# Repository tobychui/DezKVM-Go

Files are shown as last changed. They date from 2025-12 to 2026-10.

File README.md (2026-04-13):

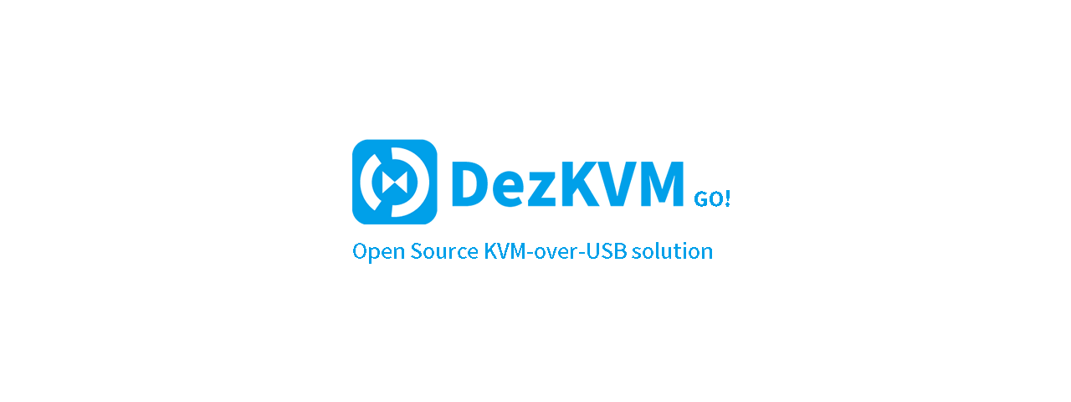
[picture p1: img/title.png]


# DezKVM-Go

A mini KVM over USB device for onsite engineers to use their laptop to control headless computers or servers.

If you are looking for an IP-KVM solution, take a look at the [DezKVM](https://github.com/tobychui/DezKVM) Project!

## Features

- Small form factor , just 84 x 53 x 18mm
- Cheap & Easy to build, costing just under $20 USD per unit
- Fully featured software that do not require installing any apps
  - Live video and audio feeds
  - Paste box (host to remote computer through automatic virtual keyboard HID events)
  - Copy via OCR (remote to host computer through OCR image to text conversion) 
  - On-screen keyboard
  - Commonly used Hot-key and macros
  - Take Screenshots
- Advanced Settings
  - Invert mouse scroll wheel direction (for Windows / MacOS cross control)
  - Absolute / Relative mode for mouse
  - Mouse Jiggler
  
## Usage

1. Insert the DezKVM-Go host side USB port into your laptop using a USB type-C cable (located on the white / black side, depends on your device casing color)
2. Insert the DezKVM-Go remote side USB port and HDMI port into the remote server or computer you want to control (located on the orange side)
3. Visit the [DezKVM-Go control panel](https://tobychui.github.io/DezKVM-Go/) or if you are working online, start the usbkvm application and visit `https://localhost:8443/` using Chrome, Edge or any Chromium browsers that support Web-Serial API.

## Quick Start

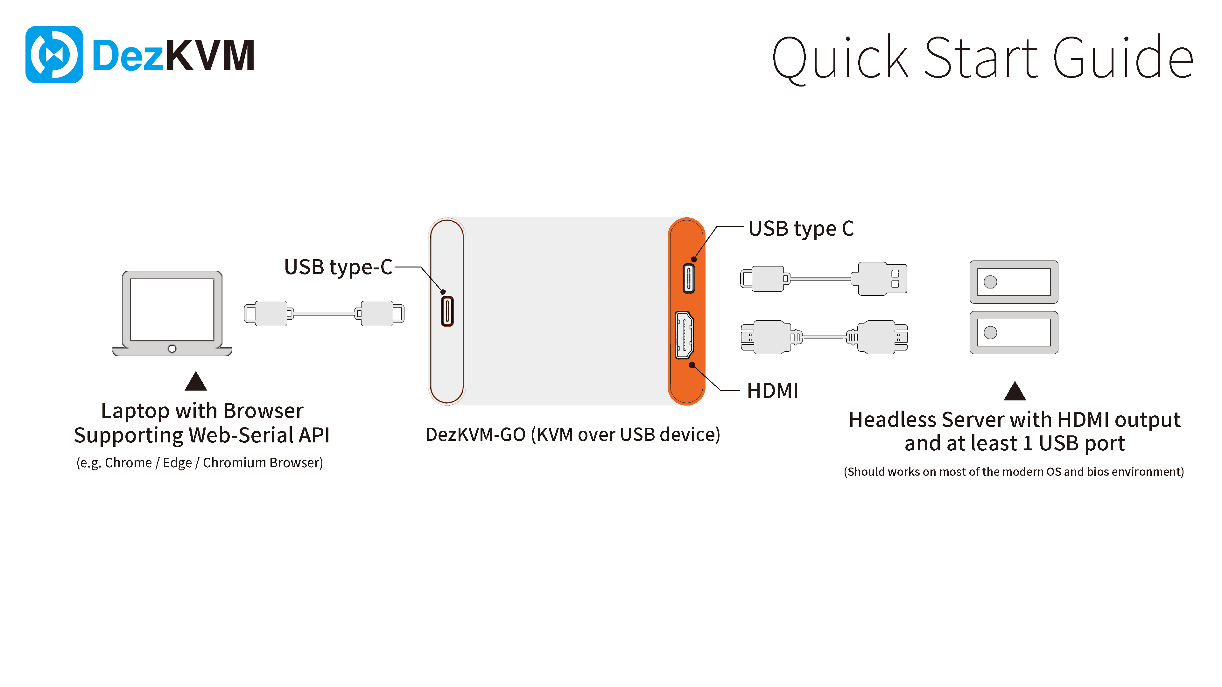
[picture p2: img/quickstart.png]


## Building the Hardware

To build the hardware, you will need the following items

- A DezKVM-Go PCB (See the `PCB` folder and the `how-to-place-order` folder on how to order them )
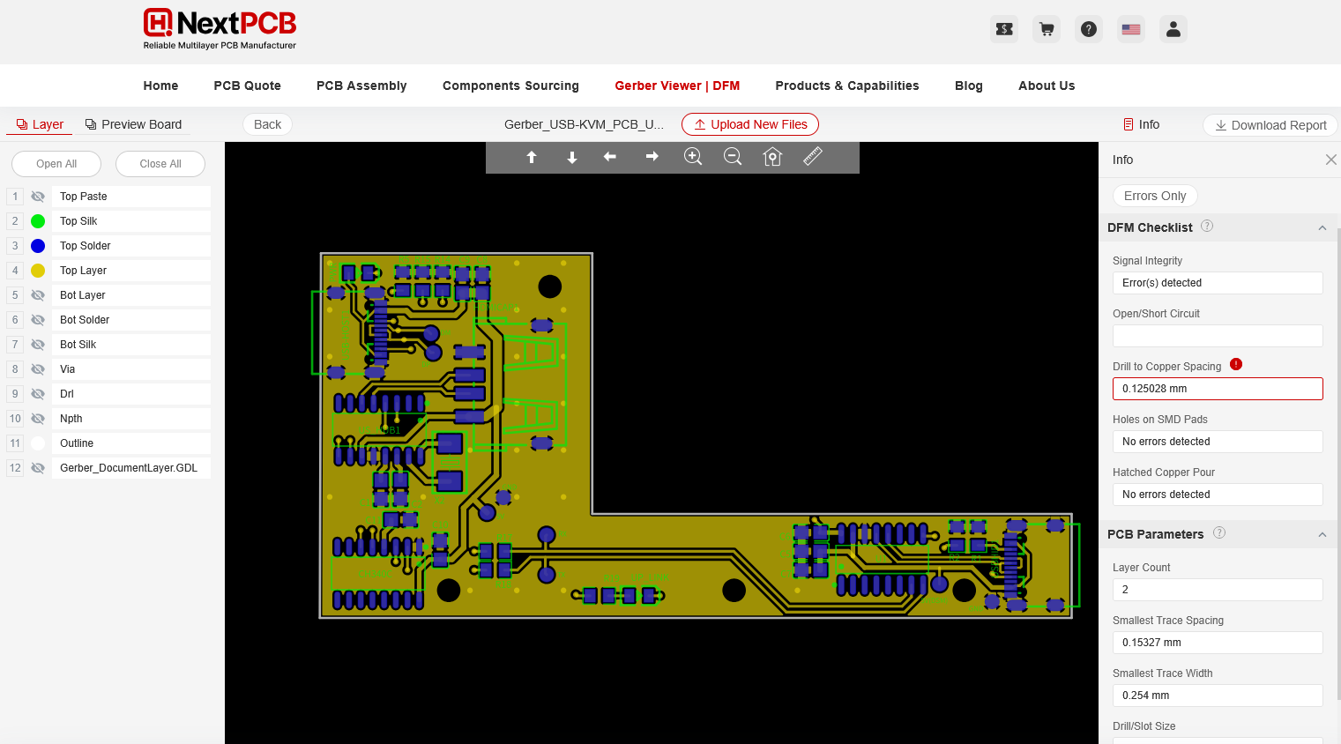
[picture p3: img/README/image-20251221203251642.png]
  
- A MS2109 HDMI capture card (usually around $7 - 9 USD a pcs)
- A 3D printer (for the case, see `3D Models` folder)
- M3x10 screws x 2
- USB type-C cable x 2 and HDMI cable x 1

For details, see the PCB folder.

## Building the Software

There is no need to build anything since all of the control code of this system is written in vanilla js in the web front-end. However, this project do come with a Golang written https server in which if you have difficulties deploying a website with https , you can use that https server to deploy a locally hosted version of the DezKVM viewer.

To build the local version of DezKVM viewer, follow the instruction below.

```bash
cd ./src
go mod tidy
go build
```

*Note: you will also need to configure the CH9329 chip to use the 115200 baudrate for the front-end to work. Please follow the instructions in CH9329 datasheet to perform the baudrate change procedures before use.*

## Screenshots

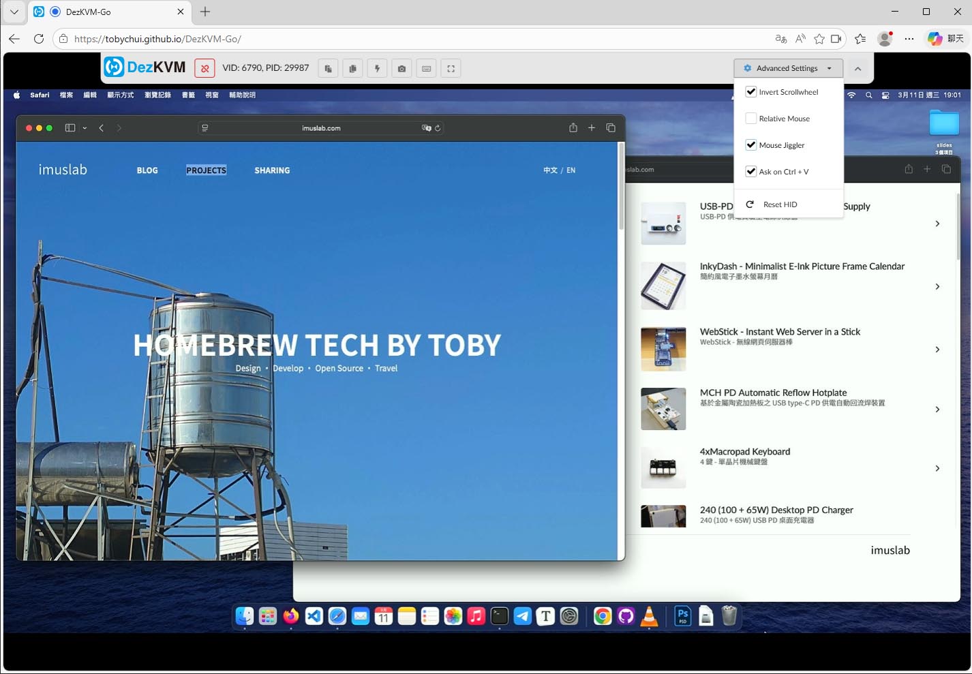
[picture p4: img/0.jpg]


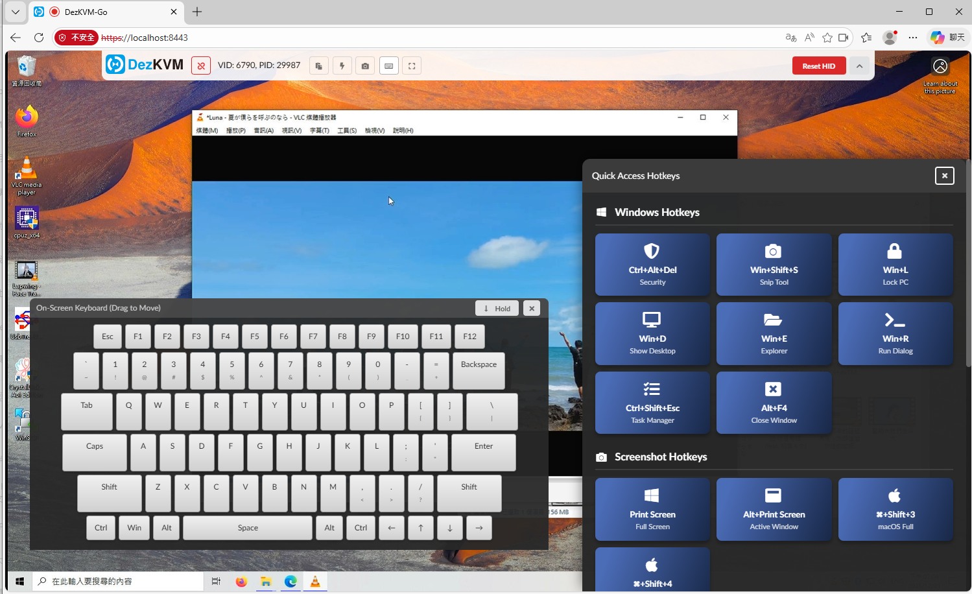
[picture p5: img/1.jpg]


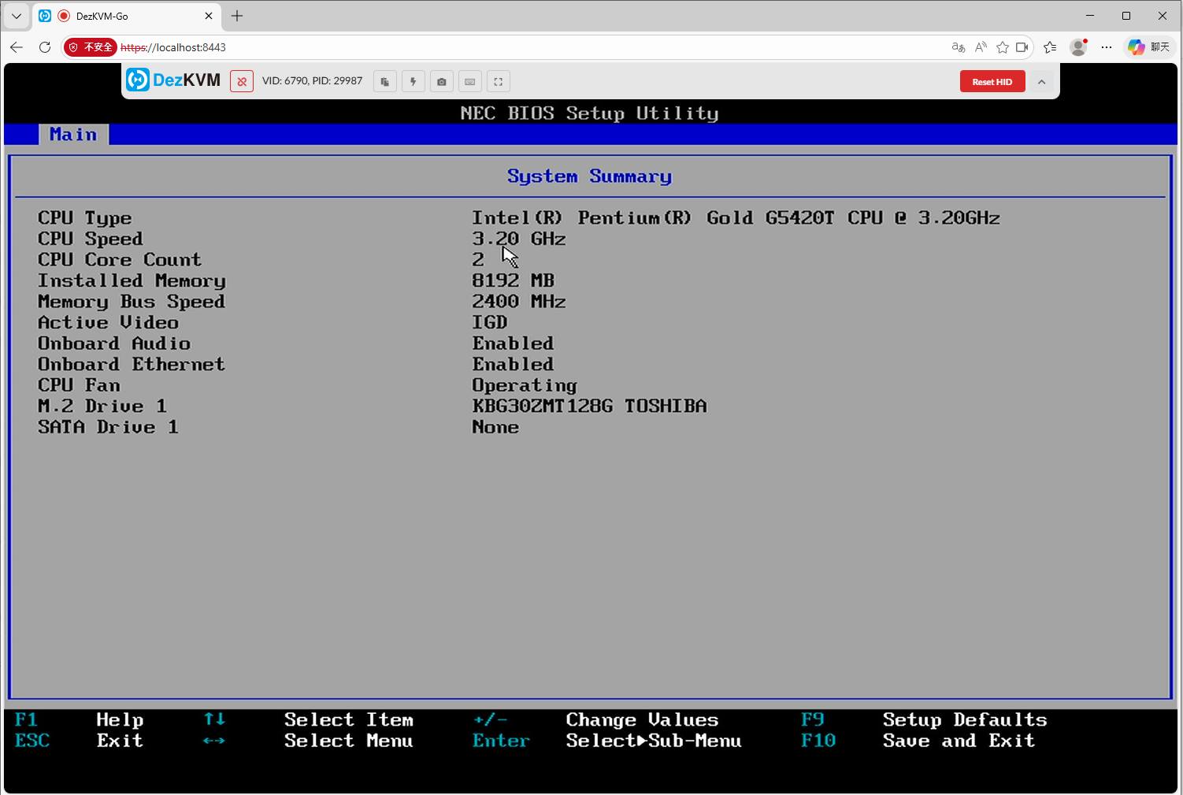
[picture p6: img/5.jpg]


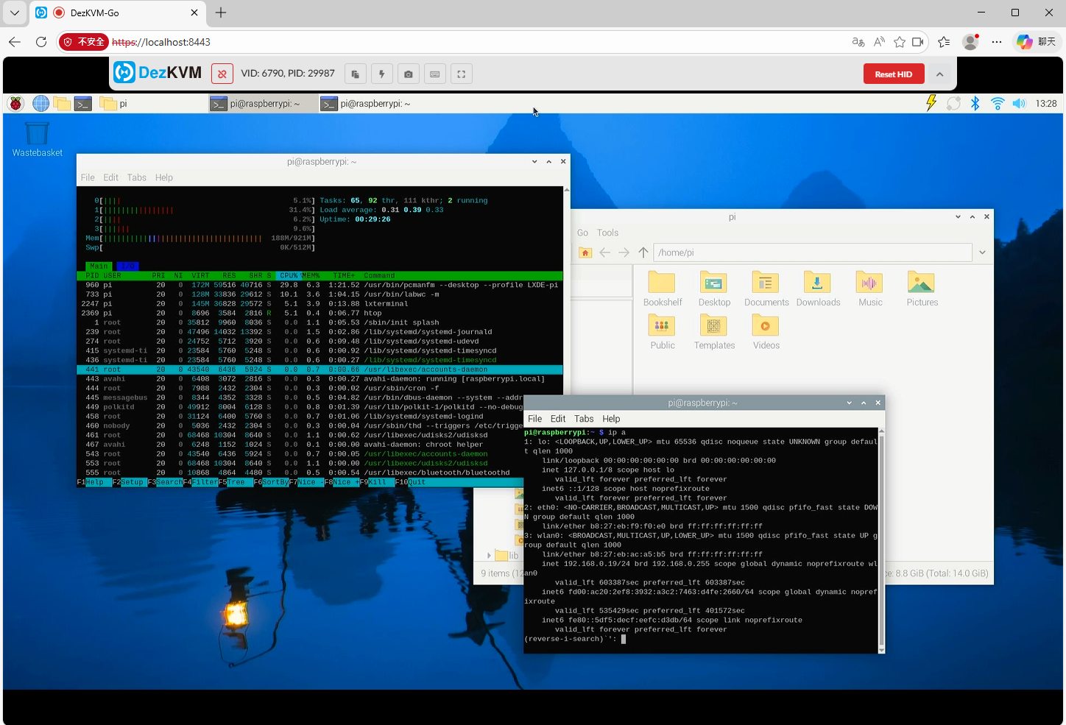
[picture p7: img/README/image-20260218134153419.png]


## DezKVM-Go Device

Here are a few photos on the device itself if you are interested.

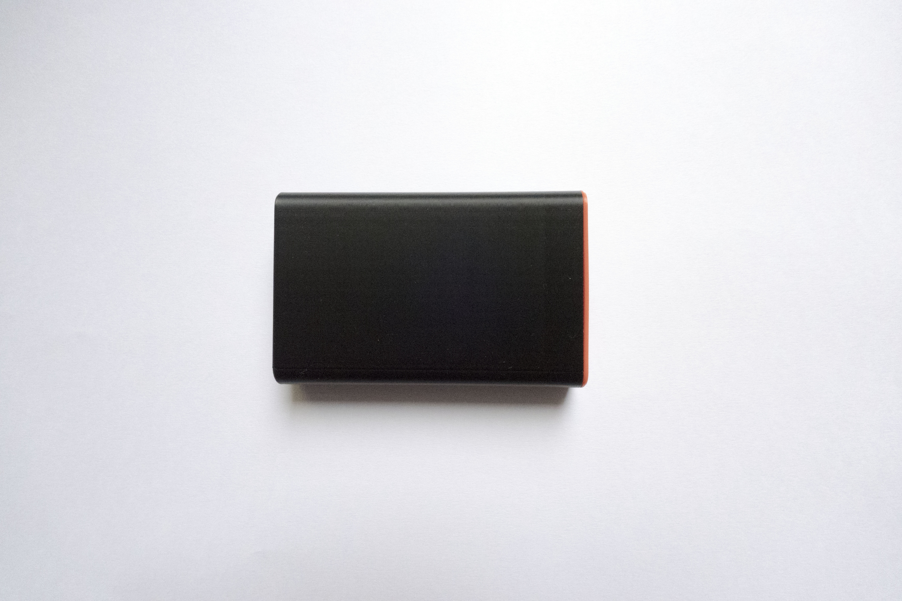
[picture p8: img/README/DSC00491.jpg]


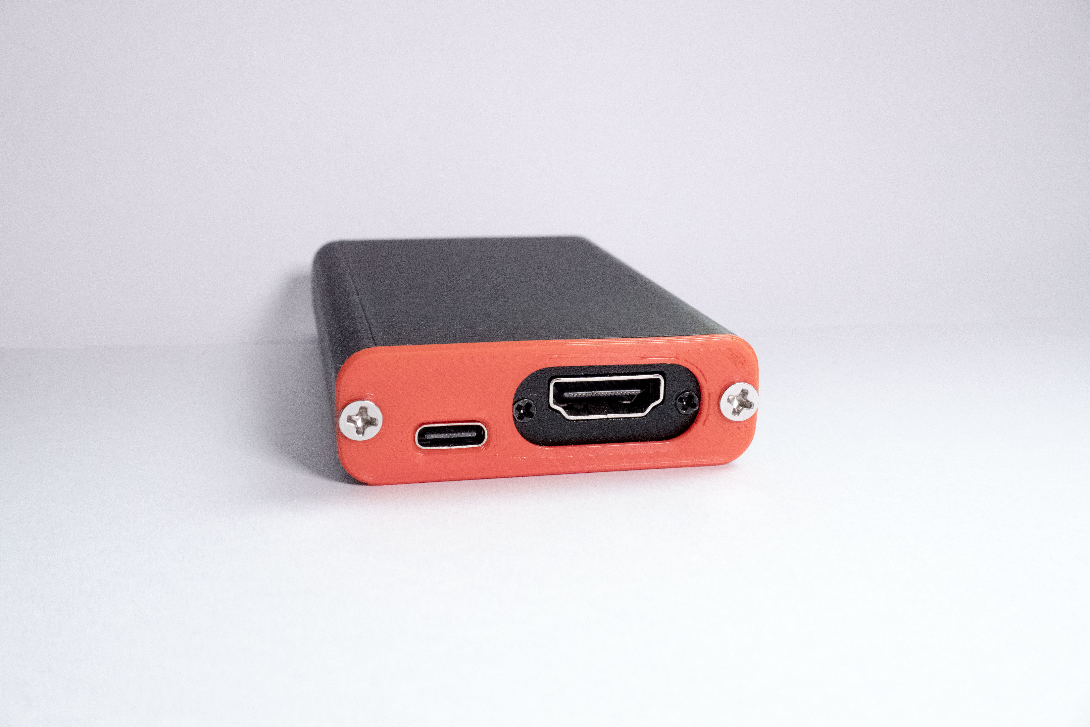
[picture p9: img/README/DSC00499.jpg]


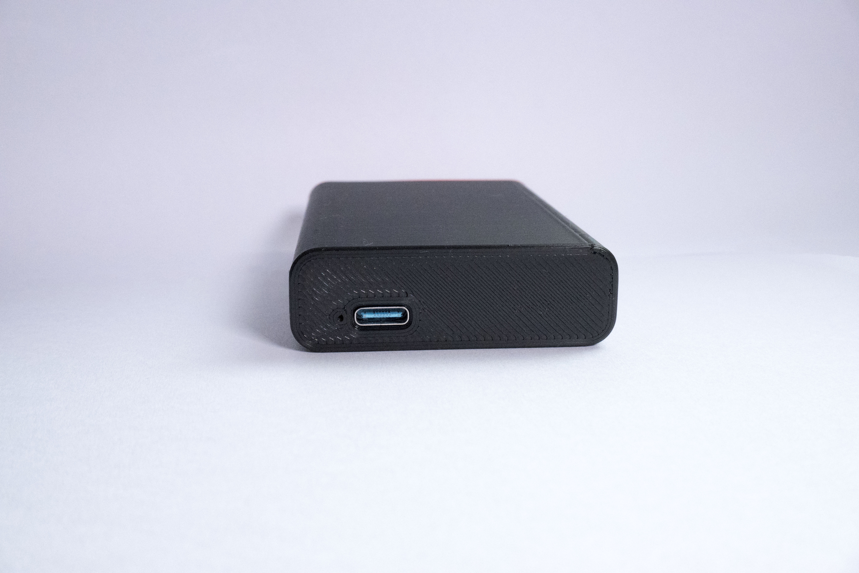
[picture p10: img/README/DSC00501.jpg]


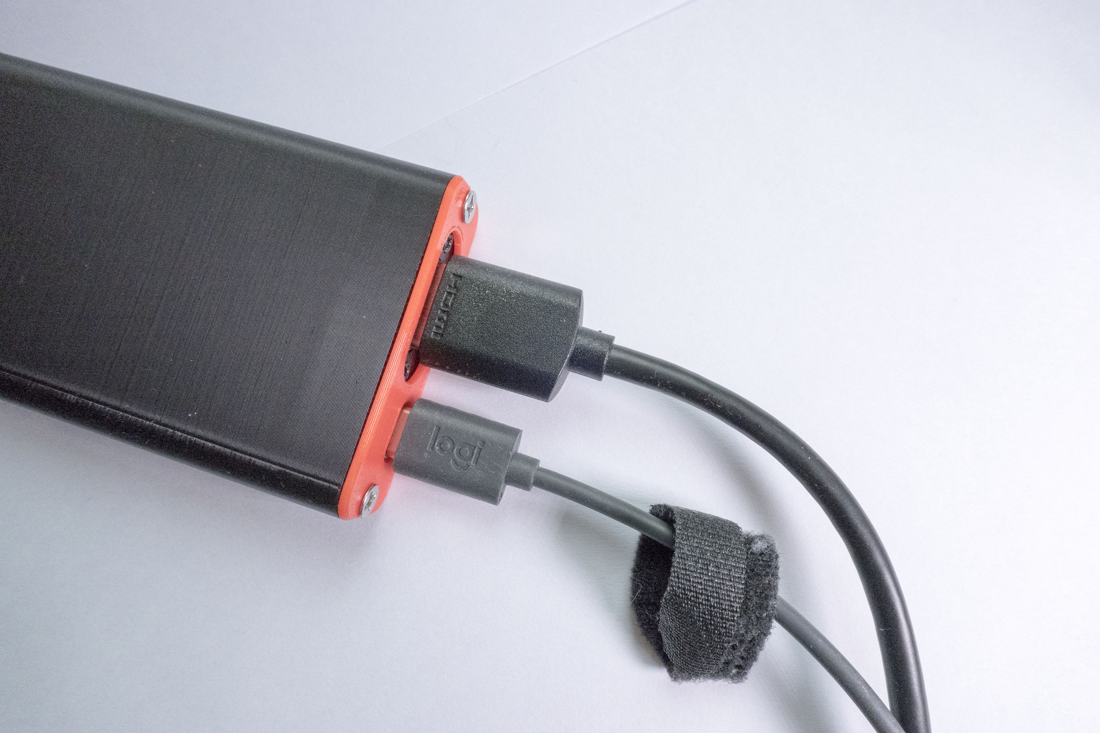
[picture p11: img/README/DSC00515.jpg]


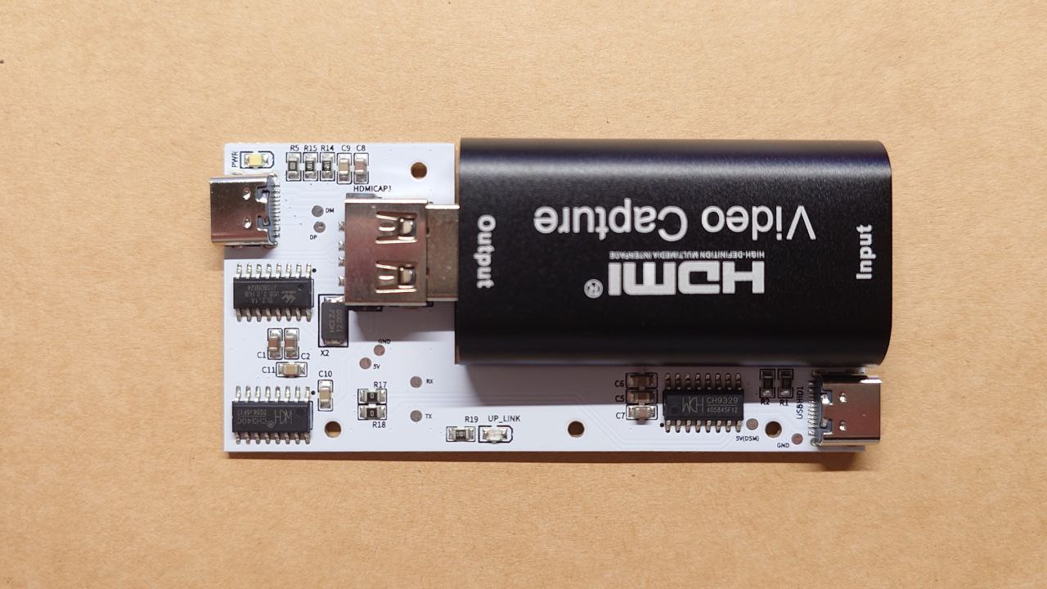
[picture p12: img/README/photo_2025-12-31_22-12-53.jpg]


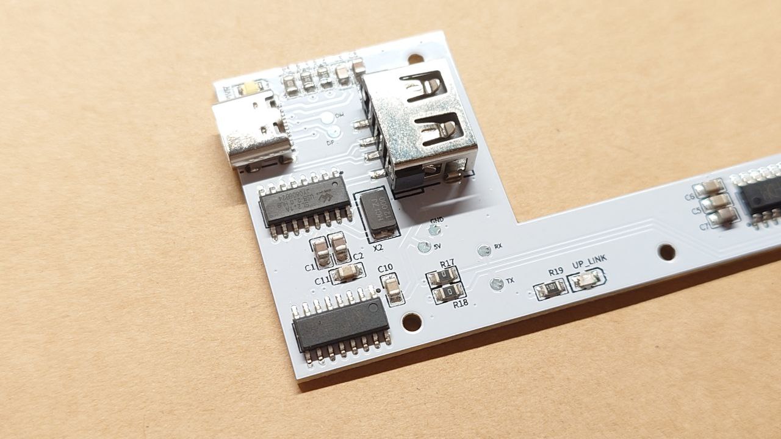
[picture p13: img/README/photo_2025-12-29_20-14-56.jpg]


### Generation 2 (MS2109S)

Due to shortage of MS2109, the HDMI capture card market are slowly shifting towards a new design of such capture card that uses MS2109S  (looks identical to the old MS2109 one, so it is hard to tell by just looking at the case of it),

In case you bought a HDMI capture card and realize it didn't fit because it is a MS2109S device, you can unscrew the metal case and use the bare PCB directly. Installation methods are as follows (notes: an additional 3D printed part and 3 x M2 x 5 screws are needed)

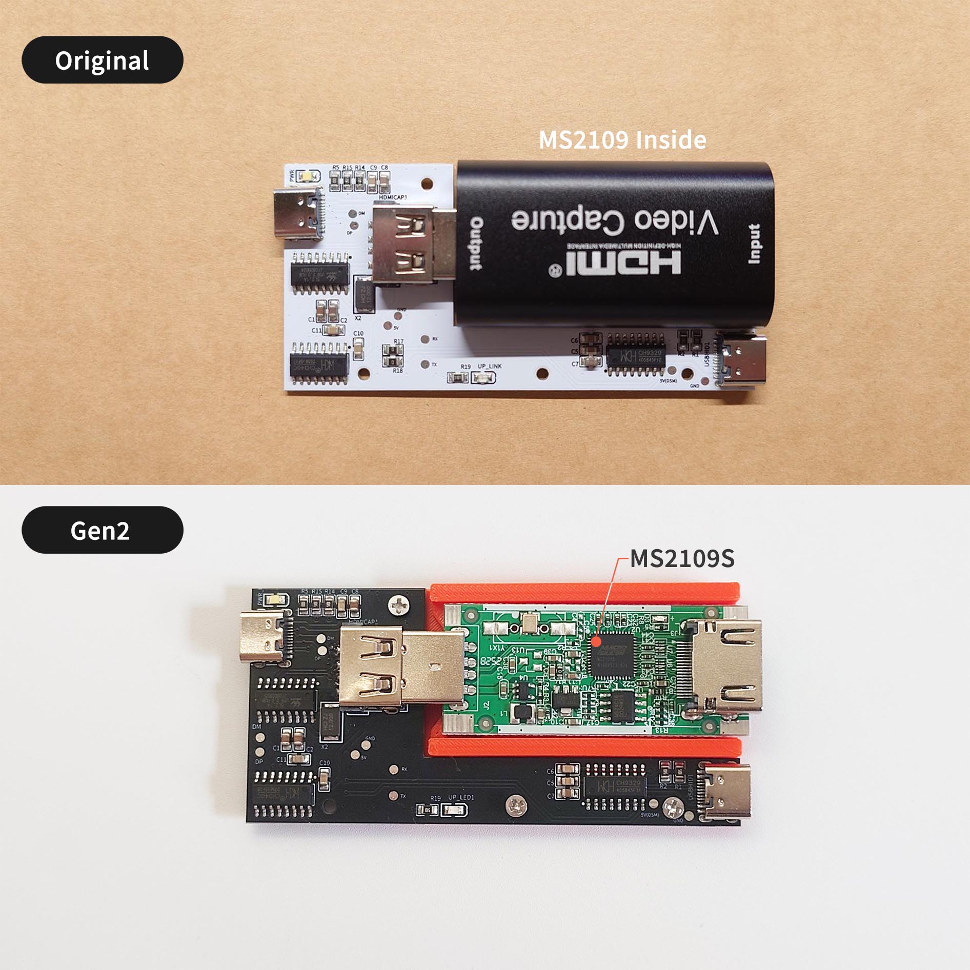
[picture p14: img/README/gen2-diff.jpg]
gen2-diff


### Buy a Ready-to-use Device

If you’d rather skip the build, I’ve put together some DezKVM Go devices that are ready to go. 

You can find them on my Tindie store (limited availability):

https://www.tindie.com/products/tobychui/dezkvm-go-kvm-over-usb-device/

## License

Software: GPLv3

Hardware: CC BY-NC-ND

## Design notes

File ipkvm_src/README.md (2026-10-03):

# DezKVM-Go — IP KVM mode

The network counterpart to the USB KVM.

In local mode the browser drives the hardware itself: WebSerial for the CH9329 and `getUserMedia` for the capture card, which means the DezKVM board has to be plugged into the machine you are sitting at. 

In IP KVM mode the board stays plugged into a Raspberry Pi (tested on RPI4), this program runs there, and any browser on the network gets the picture, the sound and the keyboard/mouse.

```
  target machine        Pi running this program with DezKVM-Go       your browser
 ┌──────────────┐  HDMI   ┌───────────────────────────────┐   HTTP  ┌───────────┐
 │              ├────────►│ MS2109(S) ──► /dev/videoN ────┼────────►│  <img>    │
 │              │         │           ──► /dev/snd/pcm…───┼── WS ──►│ WebAudio  │
 │              │◄────────┤ CH9329 ◄── CH340 ◄─ /dev/tty… │◄─ WS ───┤ key/mouse │
 └──────────────┘   USB   └───────────────────────────────┘         └───────────┘
```

## Running

```bash
cd ipkvm_src/
go run .
```

Then open `http://<pi-address>:8080`.

Everything is detected automatically, so no flags are needed in the normal case.
`start.sh` is a thin wrapper around the same thing.

### Dependencies

Raspberry Pi OS should come with all required dependencies pre-installed. In case you are using the Raspberry Pi OS Lite variant, you might need to install the following tools manually

```
sudo apt update
sudo apt install v4l-utils alsa-utils

# Optional, but maybe one day we will support WebRTC with H264 streaming?
sudo apt install ffmpeg 
```

## Command line flags

| Flag | Default | Purpose |
|---|---|---|
| `-video` | auto | Video capture node, e.g. `/dev/video0` |
| `-audio` | auto | ALSA capture PCM node, e.g. `/dev/snd/pcmC3D0c` |
| `-tty` | auto | CH9329 serial port, e.g. `/dev/ttyUSB0` |
| `-port` | `:8080` | HTTP listening address |
| `-baud` | `115200` | CH9329 serial baud rate |
| `-width` / `-height` | largest | Capture resolution |
| `-fps` | `30` | Maximum capture frame rate |
| `-jpeg-quality` | `0` (off) | Re-encode frames at this quality (5–80) to cut bandwidth |
| `-scroll-sensitivity` | `2` | Mouse wheel step sent to the CH9329 |
| `-dev` | `false` | Serve the UI from `www/` on disk instead of the embedded copy |
| `-no-hid` | `false` | Video/audio only, do not open the serial port |
| `-list-devices` | — | Print every detectable device and exit |

To start it automatically at boot, see
[Running as a service on Raspberry Pi](#running-as-a-service-on-raspberry-pi).

## Device auto detection

The kernel hands out `/dev/videoN`, `/dev/snd/pcmCxDyc` and `/dev/ttyUSBn` in
probe order, so the numbers move whenever the host boots with a different set of
USB devices attached. Instead of guessing, the detector walks sysfs and matches
on USB vendor/product IDs:

* **Video** — every `/dev/videoN` that advertises a discrete MJPEG capture format
  (which also filters out the metadata node a UVC card exposes alongside the
  streaming one), preferring a known capture chip: MacroSilicon `345f:2109`
  (MS2109S), `345f:2130`, `534d:2109`, `534d:2130`.
* **Audio** — the capture card puts its video and audio interfaces on the *same*
  USB device, so the PCM node is simply the sound card hanging off the same USB
  device directory as the video node.
* **Serial** — a WCH bridge (`1a86:7523` CH340, `1a86:5523` CH341, `1a86:7522`,
  `1a86:55d4` CH9102). When several are present, the one on the same internal hub
  as the capture card wins, since that is how a DezKVM board is wired.

Each tier falls back to "first plausible device" if nothing is recognised, and
`-list-devices` shows what was found:

```
$ go run . -list-devices
Video capture devices (MJPEG capable):
  * /dev/video0    345f:2109    UVC Camera (345f:2109): USB Vid

Audio capture devices:
  * /dev/snd/pcmC3D0c      345f:2109    U0x345f0x2109

Serial ports:
  * /dev/ttyUSB0   1a86:7523

  (* = recognised DezKVM hardware)
```

## HTTP interface

| Endpoint | Purpose |
|---|---|
| `GET /` | Web UI |
| `GET /api/video/stream` | `multipart/x-mixed-replace` MJPEG stream |
| `GET /api/video/screenshot` | Single JPEG frame |
| `GET /api/video/resolutions` | Supported MJPEG sizes and frame rates |
| `POST /api/video/resolution?width=&height=&fps=` | Change the capture format |
| `GET /api/status` | Device nodes, capture state, stream info |
| `POST /api/hid/reset` | CH9329 soft reset + release all modifiers |
| `POST /api/hid/jiggler?enable=` | Server-side mouse jiggler |
| `GET /ws/hid` | JSON HID events (see `mod/kvmhid/typedef.go`) |
| `GET /ws/audio?quality=low\|standard\|high` | Raw S16LE stereo PCM |

Audio quality also picks the sample rate, because the backend downsamples by
dropping frames: `high` = 48kHz, `standard` = 24kHz, `low` = 16kHz.

### Screenshots

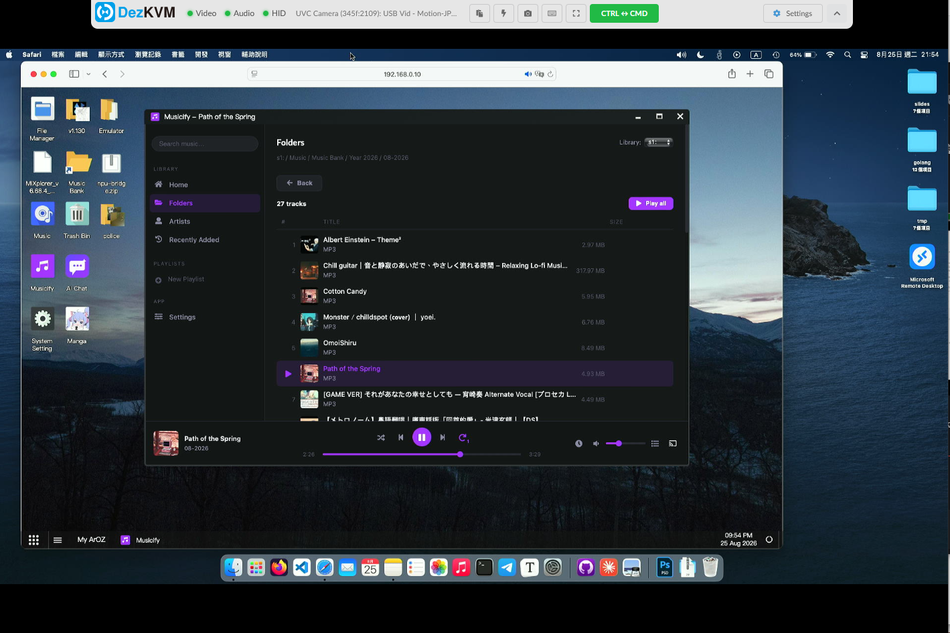
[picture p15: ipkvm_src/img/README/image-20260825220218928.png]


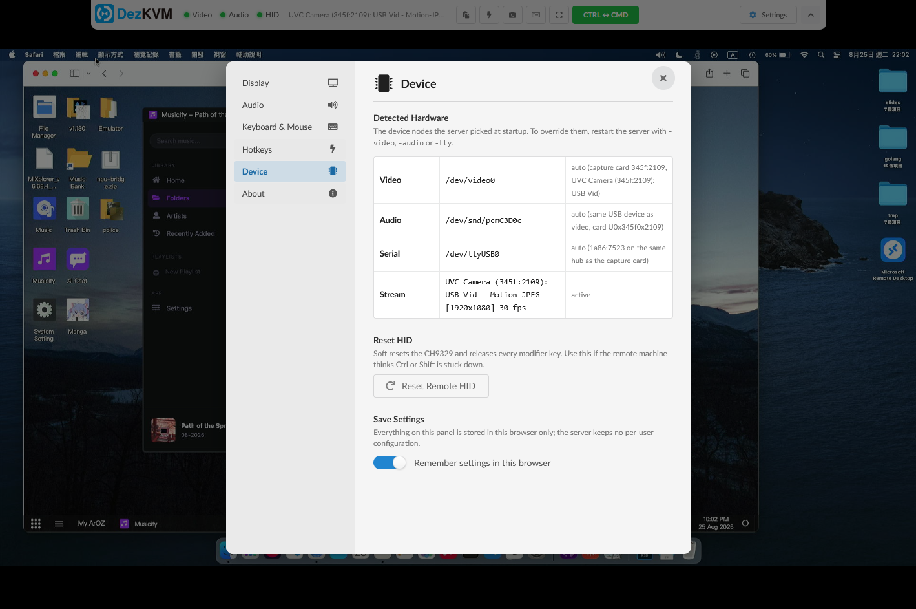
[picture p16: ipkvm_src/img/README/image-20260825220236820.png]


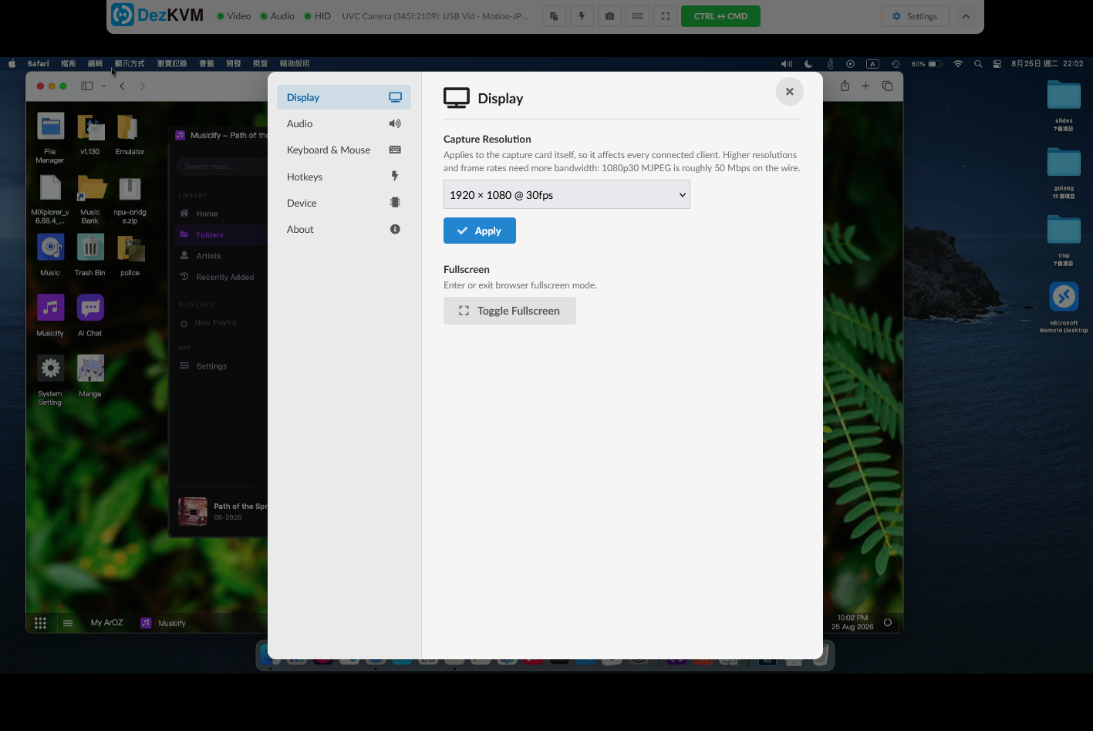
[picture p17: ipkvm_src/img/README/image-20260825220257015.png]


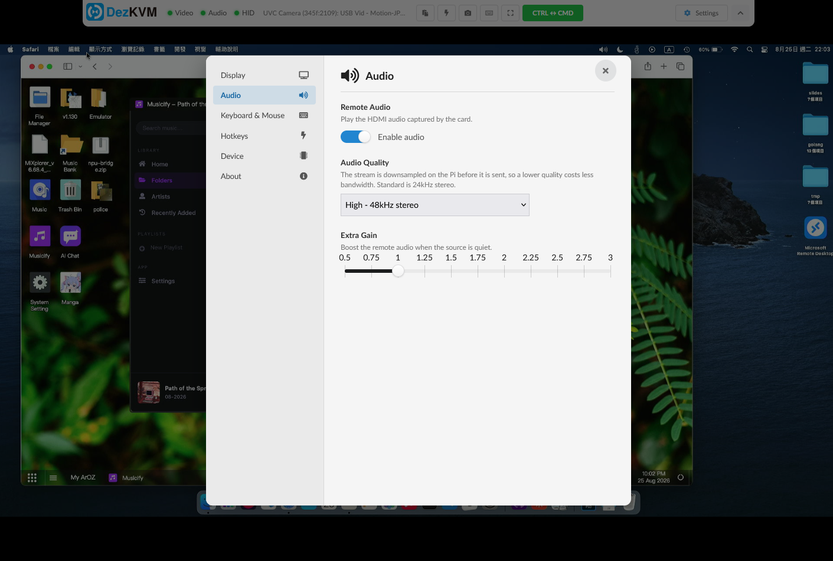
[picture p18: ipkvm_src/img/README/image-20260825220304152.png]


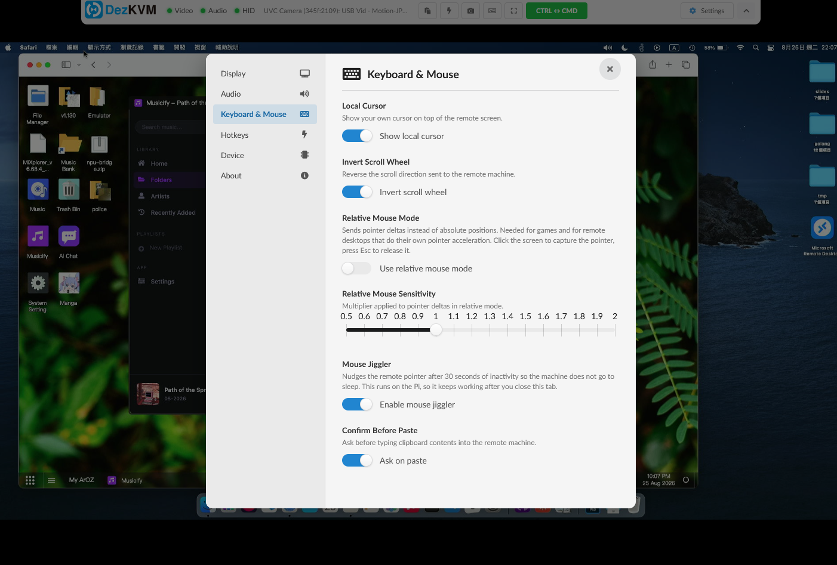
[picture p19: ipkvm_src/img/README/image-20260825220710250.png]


## Running as a service on Raspberry Pi

`dezkvm-ipkvm.service` is a ready-to-edit systemd unit that starts the KVM at
boot. Build the binary, put it somewhere permanent, then install the unit:

```bash
# 1. Build a standalone binary (the web UI is embedded, so this one file is all
#    you need at runtime - no www/ folder, no go toolchain)
cd ipkvm_src
go build -o dezkvm-ipkvm .

# 2. Install it
sudo mkdir -p /opt/dezkvm-ipkvm
sudo cp dezkvm-ipkvm /opt/dezkvm-ipkvm/

# 3. Install the unit
sudo cp dezkvm-ipkvm.service /etc/systemd/system/
sudo systemctl daemon-reload
sudo systemctl enable --now dezkvm-ipkvm
```

Check that it came up:

```bash
systemctl status dezkvm-ipkvm
journalctl -u dezkvm-ipkvm -f
```

The log should name the three device nodes it picked, the same as running it by
hand.

### Editing the unit

The shipped file assumes the binary is at `/opt/dezkvm-ipkvm/dezkvm-ipkvm` and
runs as user `pi`. Change `User=`, `WorkingDirectory=` and `ExecStart=` if that
does not match your setup, then `sudo systemctl daemon-reload`.

Extra flags go on the `ExecStart=` line, for example to move it off port 8080
and cut the bitrate:

```ini
ExecStart=/opt/dezkvm-ipkvm/dezkvm-ipkvm -port :9000 -jpeg-quality 60
```

### Permissions

The service does not run as root. Access to the three device nodes comes from
group membership instead, which the unit requests via `SupplementaryGroups=`:

| Device | Group |
|---|---|
| `/dev/videoN` | `video` |
| `/dev/snd/pcmCxDyc` | `audio` |
| `/dev/ttyUSBn` | `dialout` |

On Raspberry Pi OS the `pi` user is already in all three. For a different user:

```bash
sudo usermod -aG video,audio,dialout <user>
```

`PrivateDevices=` is deliberately *not* set in the unit - it would hide exactly
the device nodes the service needs.

### Cold boot timing

USB enumeration is not finished the instant systemd reaches `multi-user.target`,
so on a cold boot the capture card may not exist yet. The unit handles this two
ways: an `ExecStartPre=/bin/sleep 5` before the first attempt, and
`Restart=on-failure` with `RestartSec=5` in case that is still not enough. If
your board is consistently slower, raise the sleep.

If you would rather have systemd wait for the hardware itself than sleep, drop
the `ExecStartPre` and bind the unit to the device instead:

```ini
BindsTo=dev-ttyUSB0.device
After=dev-ttyUSB0.device
```

That ties the service to one fixed node name though, which is the very thing the
auto detection exists to avoid, so it is only worth doing on a board where
nothing else is ever plugged in.

### Stopping and removing

```bash
sudo systemctl disable --now dezkvm-ipkvm
sudo rm /etc/systemd/system/dezkvm-ipkvm.service
sudo systemctl daemon-reload
```

## Self Hosting Notes

T**his IP-KVM mode implementation for DezKVM-Go device contains no authentication system nor it serve it contents in encrypted (HTTPS). If you want to expose this to the internet, you must introduce some sort of authentication gateway and proxy the traffic using HTTPS for security reasons.** 

If you are looking for an easy to use and feature rich reverse proxy server, feel free to checkout [Zoraxy](https://zoraxy.aroz.org) which got builds in ACME tools for getting free HTTPS certificate as well as Zoraxy Auth SSO system.

## License

AGPL

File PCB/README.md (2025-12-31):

## Making your own DezKVM-GO Hardware

Making your DezKVM Go hardware is not difficult. What you need is to send the PCB to print. If you have the budget, you can even go the full PCBA route and make a ready to use product with the help of [NextPCB](https://www.nextpcb.com/?code=tobychui/C) (sponsor of this project)

### PCB Photoshoots

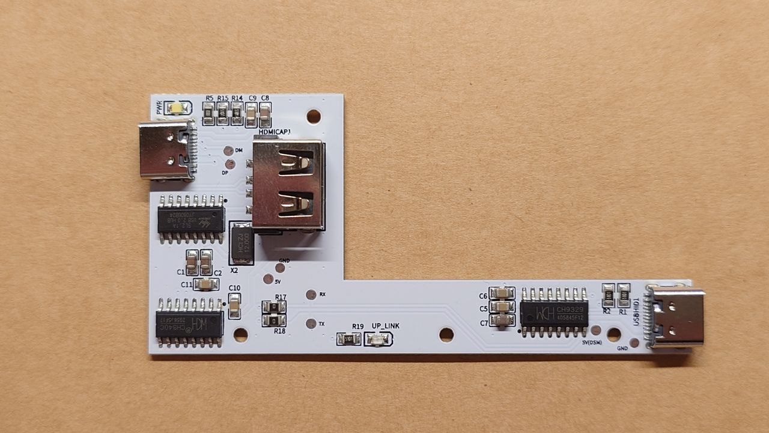
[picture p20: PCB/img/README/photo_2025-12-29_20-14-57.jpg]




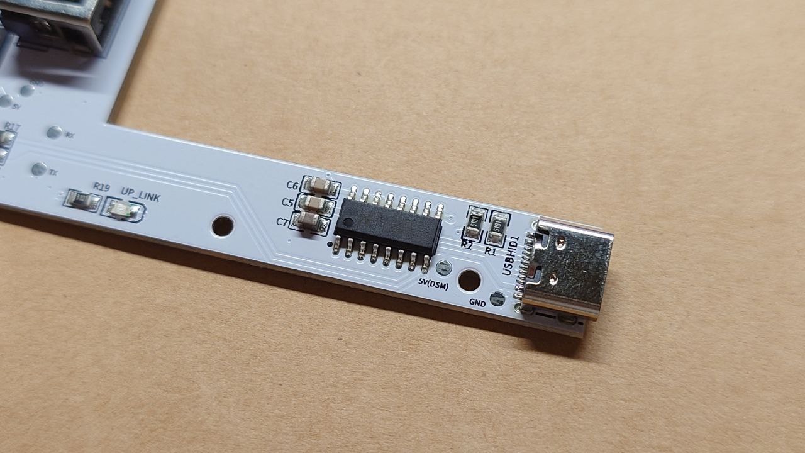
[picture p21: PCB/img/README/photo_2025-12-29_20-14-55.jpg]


That cutout is for the MS2109 HDMI capture card. You can easily find one on Amazon for around 9 - 12USD. After inserting the capture card, the whole circuit should looks like this.



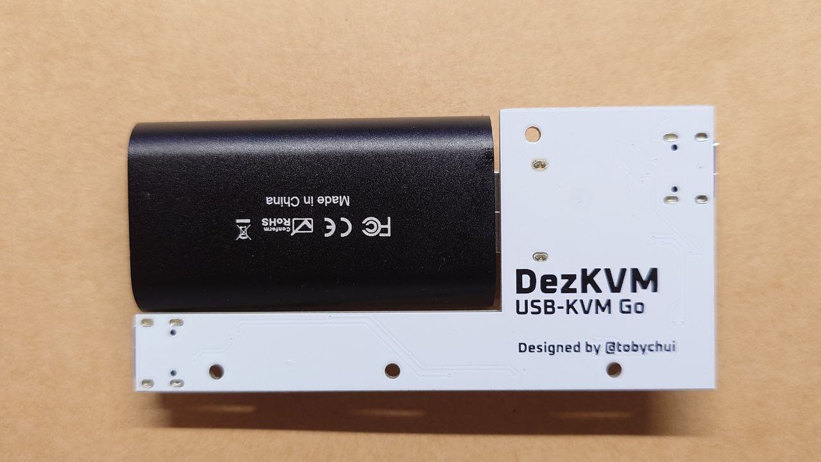
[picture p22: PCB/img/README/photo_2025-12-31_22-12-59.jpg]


### What PCB manufacturing parameters should I pick?

Here are the parameters and properties I pick for making the PCB above. You can upload the Gerber file to [NextPCB](https://www.nextpcb.com/?code=tobychui/C) website and following the options in the screenshot below to make yours.

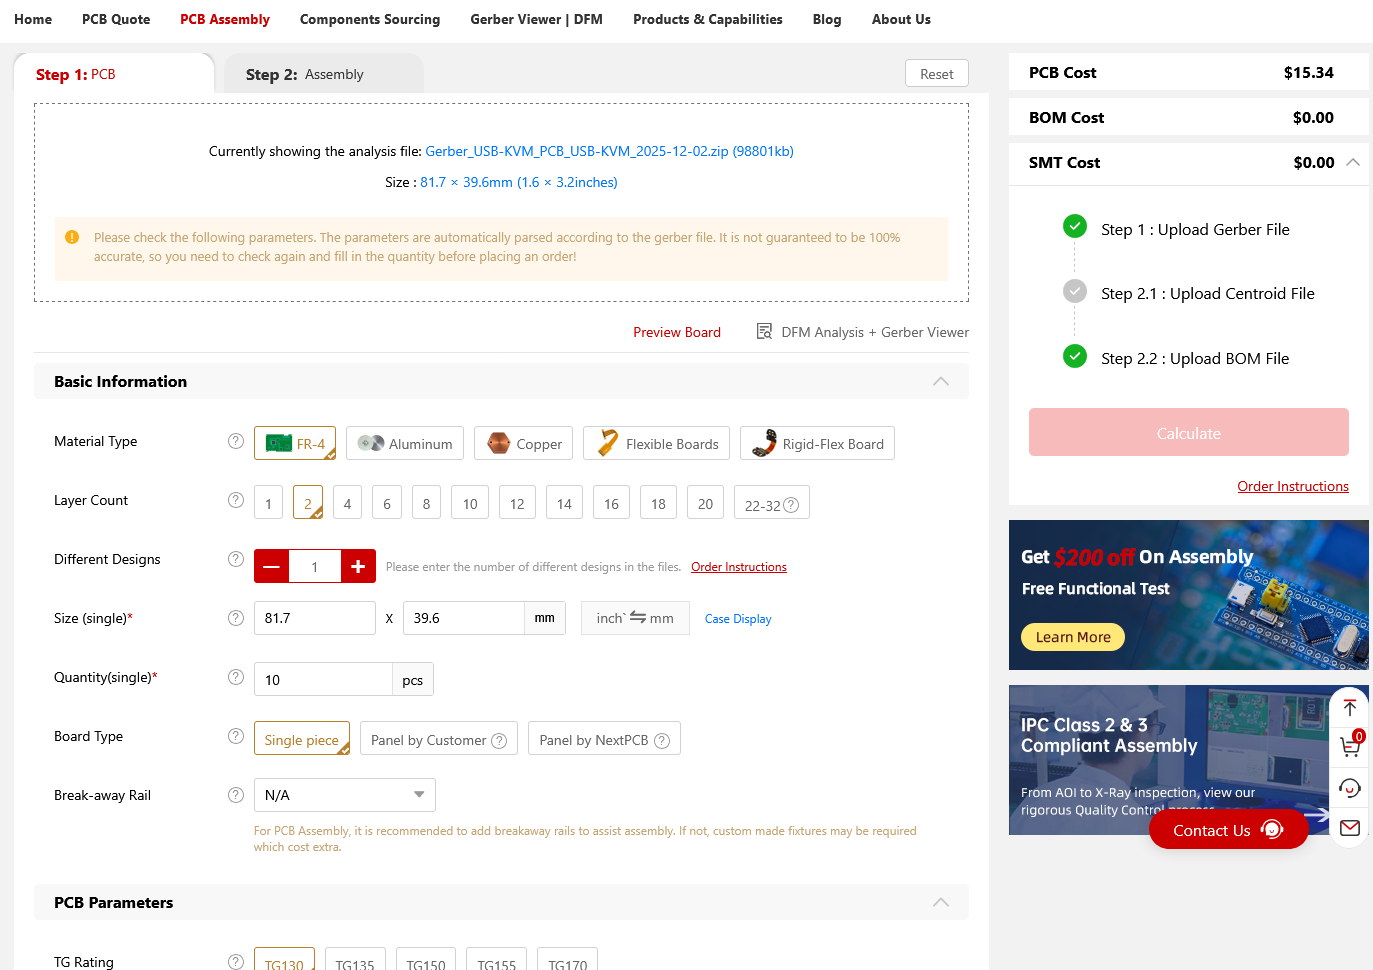
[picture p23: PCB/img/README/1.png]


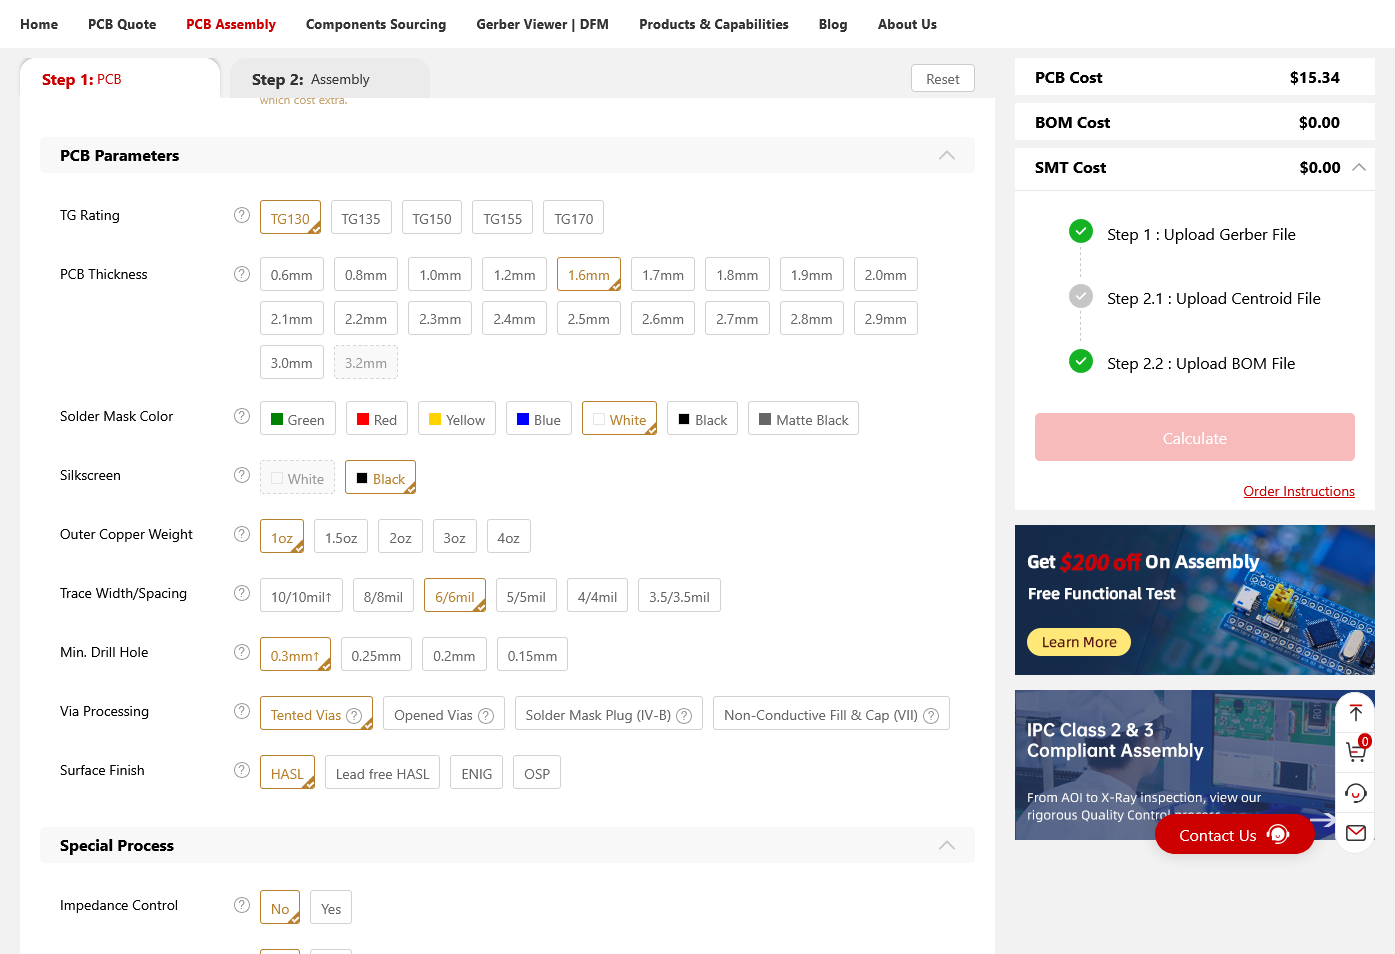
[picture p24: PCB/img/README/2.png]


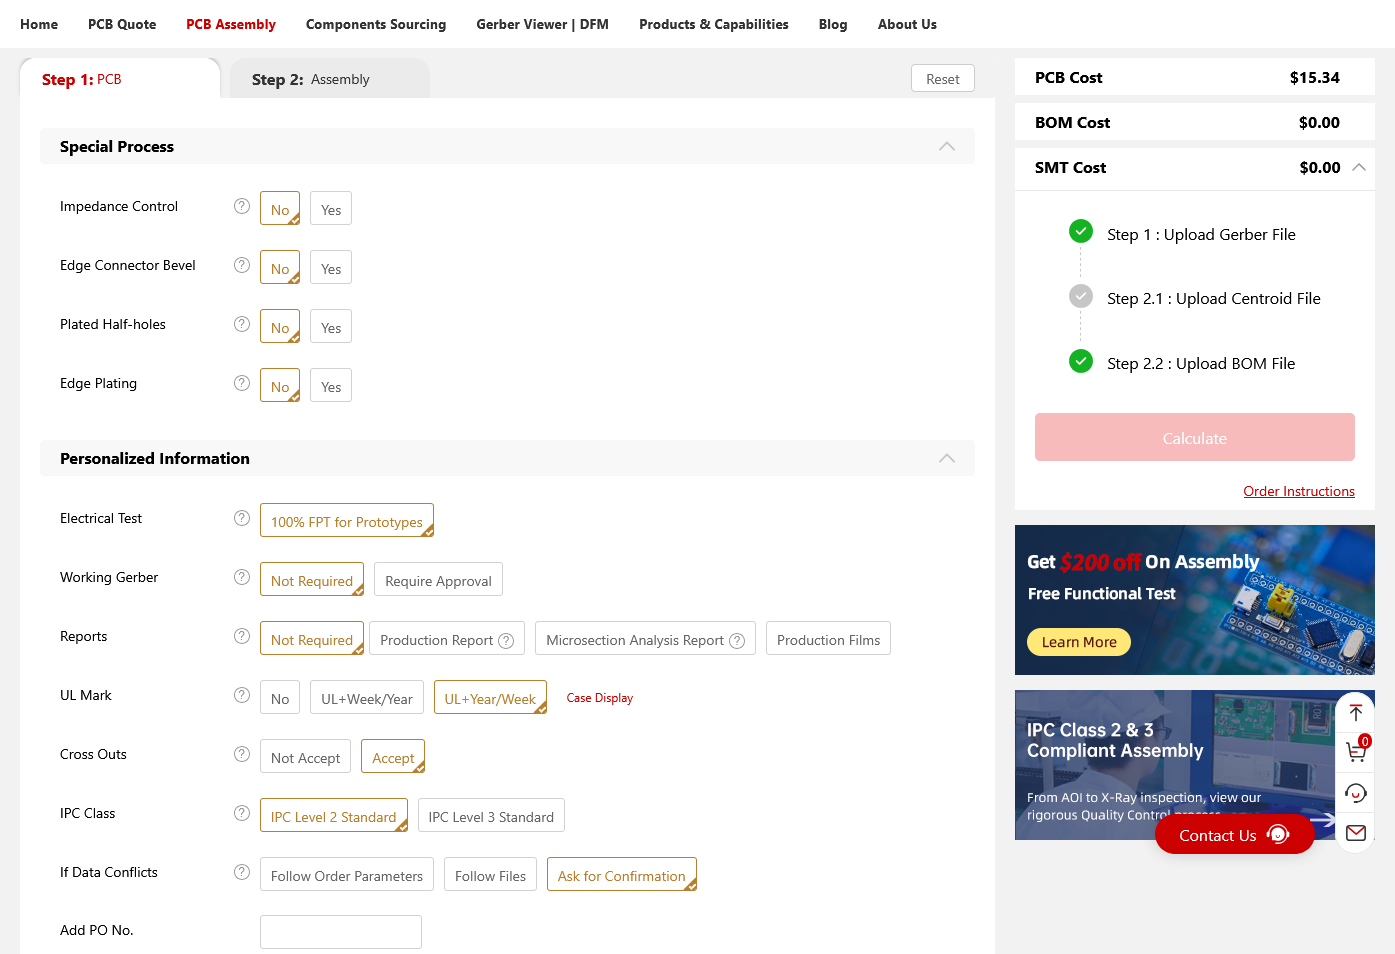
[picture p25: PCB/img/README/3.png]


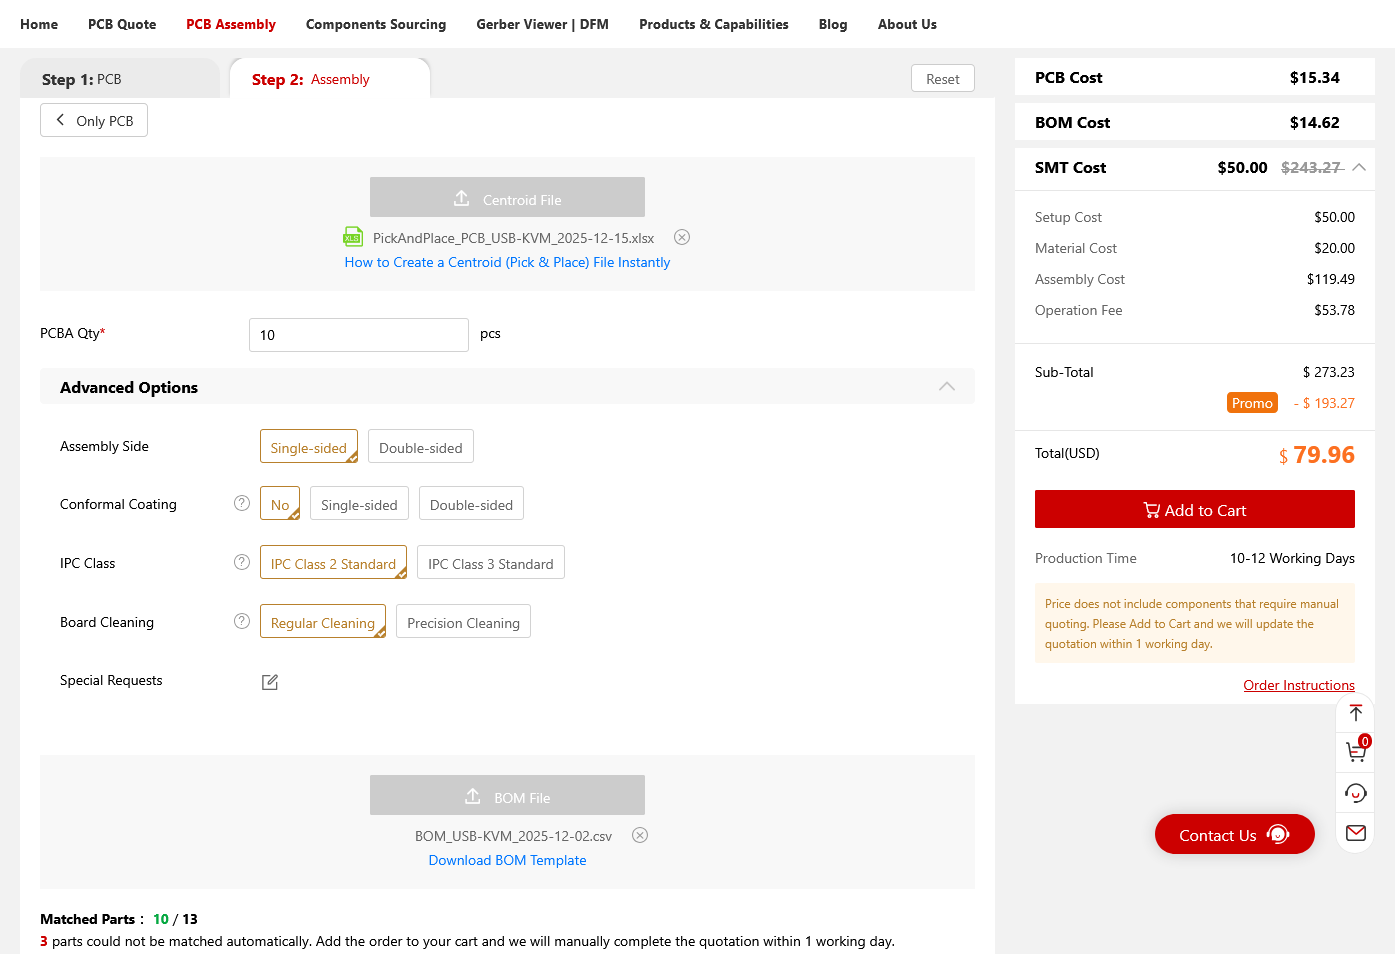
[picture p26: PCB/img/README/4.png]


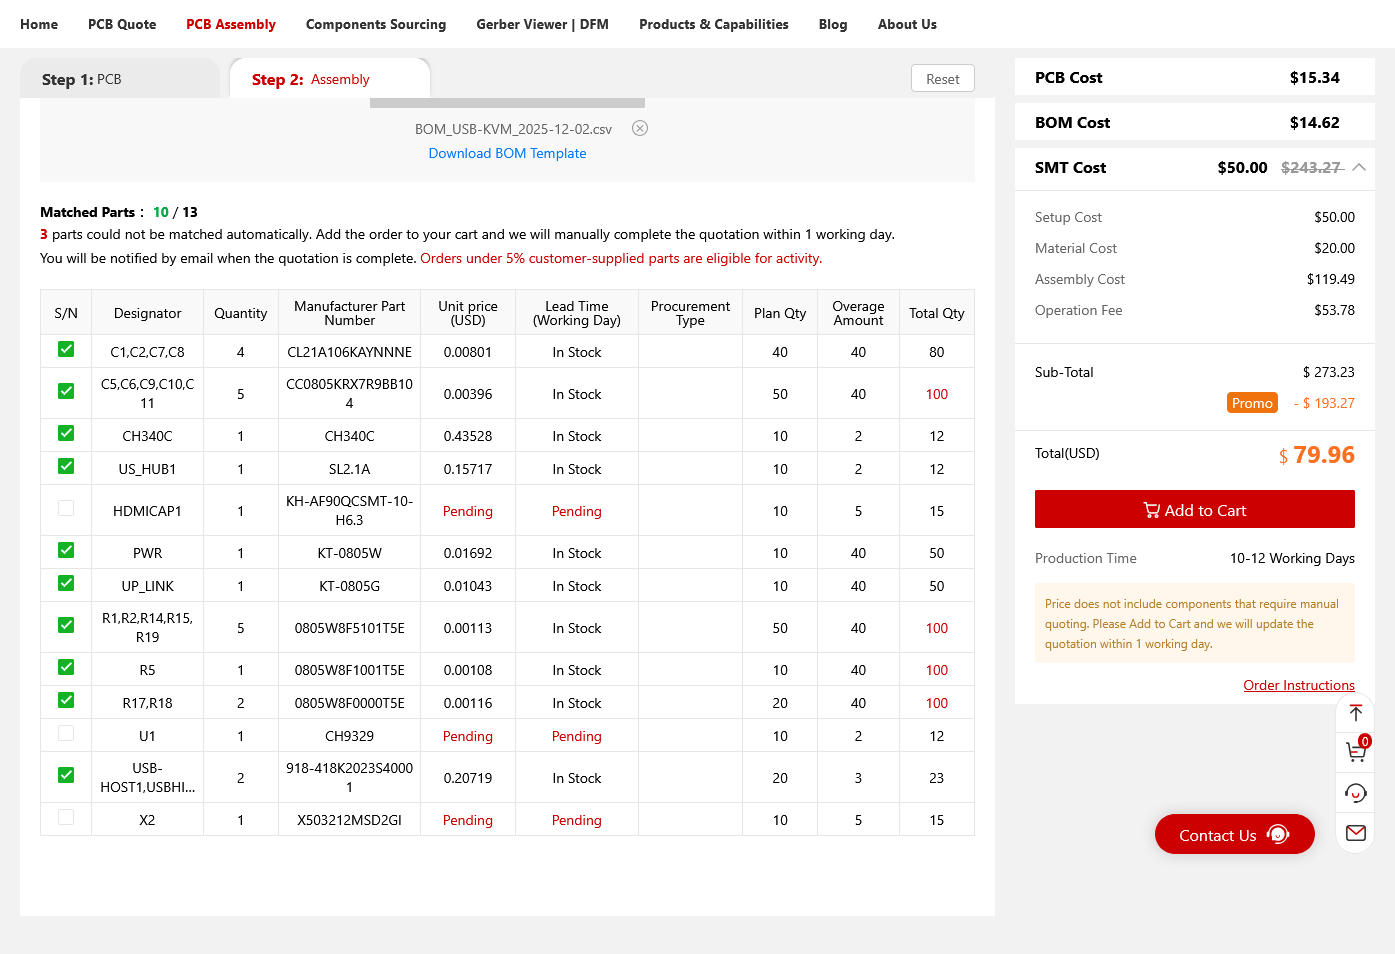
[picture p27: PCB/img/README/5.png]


For details, see the BOM list and Gerber files.

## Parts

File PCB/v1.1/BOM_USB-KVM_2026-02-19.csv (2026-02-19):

ID | Name | Designator | Footprint | Quantity | Manufacturer Part | Manufacturer | Supplier | Supplier Part | Price
1 | 0Ω | R3/NC | R0805 | 1 | YLRY05-W2-0Z | yezhan(业展) | LCSC | C22468035 | 0.039
2 | whiteLEDSMD | PWR_LED1 | LED0805-R-RD | 1 | KT-0805W | KENTO | LCSC | C34499 | 0.02
3 | 0805G (Green) | UP_LED1 | LED0805-R-RD | 1 | KT-0805G | KENTO | LCSC | C2297 | 0.016
4 | 10uF | C1,C2,C7,C8 | C0805 | 4 | CL21A106KAYNNNE | SAMSUNG(三星) | LCSC | C15850 | 0.016
5 | 100nF | C5,C6,C9,C10,C11 | C0805 | 5 | CC0805KRX7R9BB104 | YAGEO(国巨) | LCSC | C49678 | 0.005
6 | CH340C | CH340C | SOP-16_L10.0-W3.9-P1.27-LS6.0-BL | 1 | CH340C | WCH(南京沁恒) | LCSC | C84681 | 0.572
7 | SL2.1A | US_HUB1 | SOP-16_L10.0-W3.9-P1.27-LS6.0-BL | 1 | SL2.1A | CoreChips(和芯润德) | LCSC | C192893 | 0.241
8 | KH-AF90QCSMT-10-H6.3 | HDMICAP1 | USB-A-SMD_KH-AF90QCSMT-10-H6.3 | 1 | KH-AF90QCSMT-10-H6.3 | kinghelm(金航标) | LCSC | C2979063 | 0.044
9 | 5.1kΩ | R1,R2,R14,R15,R19 | R0805 | 5 | 0805W8F5101T5E | UNI-ROYAL(厚声) | LCSC | C27834 | 0.002
10 | 1kΩ | R5 | R0805 | 1 | 0805W8F1001T5E | UNI-ROYAL(厚声) | LCSC | C17513 | 0.002
11 | CH9329 | U1 | SOP-16_L9.9-W3.9-P1.27-LS6.0-BL | 1 | CH9329 | WCH(南京沁恒) | LCSC | C2838834 | 1.282
12 | USB3.1C16PFSMT | USB-HOST1,USBHID1 | USB-C-SMD_TYPE-C-USB-17 | 2 | 918-418K2023S40001 | 精拓金 | LCSC | C167321 | 0.393
13 | 12MHz | X2 | OSC-SMD_L5.0-W3.2 | 1 | X503212MSD2GI | YXC(扬兴晶振) | LCSC | C114436 | 0.22

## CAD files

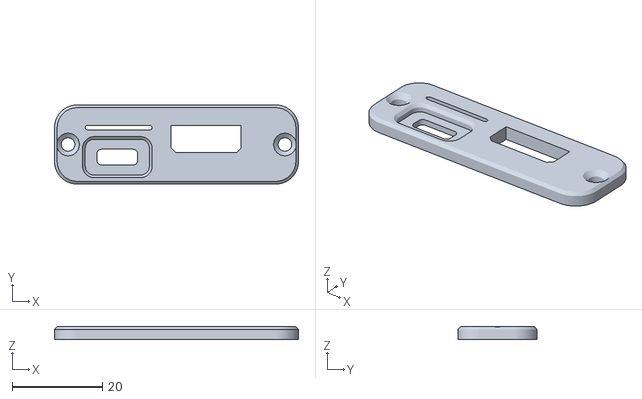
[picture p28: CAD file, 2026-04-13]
3D Models/cover-gen2.stl
54.0 x 17.5 x 2.80

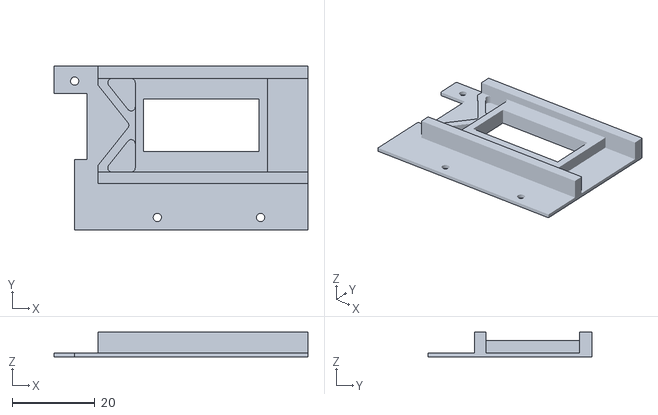
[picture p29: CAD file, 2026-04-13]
3D Models/gen2-hdmi-mount.stl
61.5 x 39.6 x 6.00

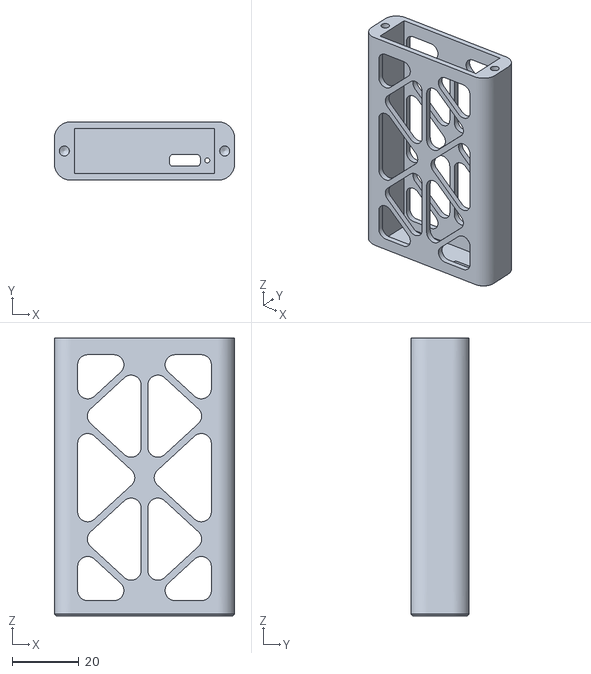
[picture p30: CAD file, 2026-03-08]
3D Models/base-open-frame.stl
54.0 x 17.5 x 83.2

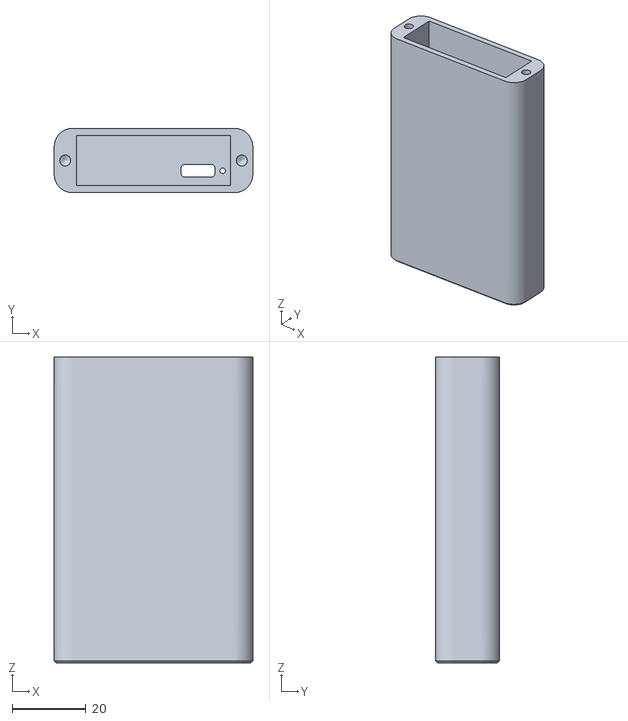
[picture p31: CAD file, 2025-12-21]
3D Models/base.stl
54.0 x 17.5 x 83.2

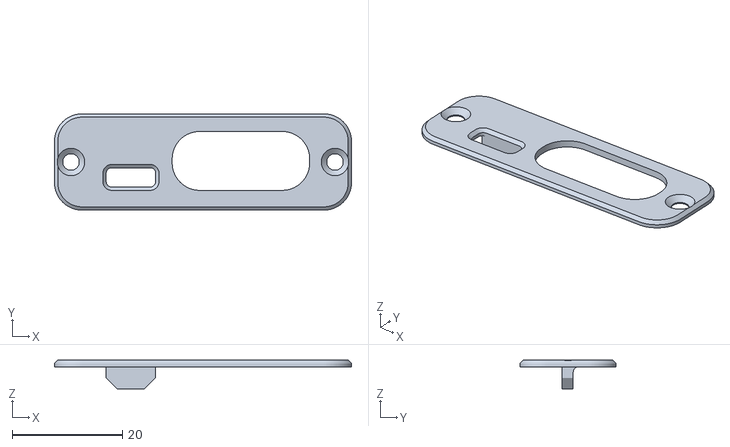
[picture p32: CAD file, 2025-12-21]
3D Models/cover.stl
54.0 x 17.5 x 5.20

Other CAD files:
3D Models/base-open-frame.ipt
3D Models/base.ipt
3D Models/cover-gen2.ipt
3D Models/cover.ipt
3D Models/gen2-hdmi-mount.ipt
3D Models/test_Fit.iam

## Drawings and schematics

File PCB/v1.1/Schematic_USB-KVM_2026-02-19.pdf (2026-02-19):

# VBUS A4 CC1 A5 DP1 A6 DN1 A7 SBU1 A8 VBUS A9

## Power Ripple Filter

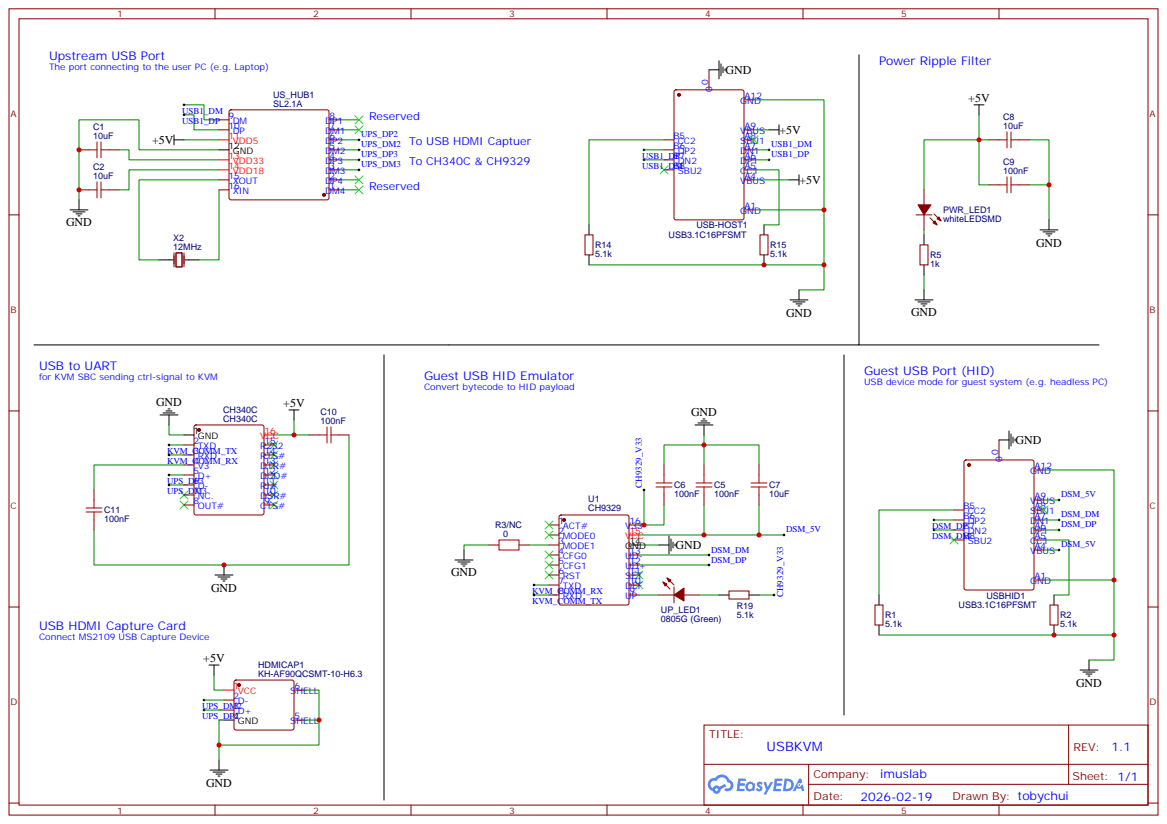
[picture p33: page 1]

Upstream USB Port
The port connecting to the user PC (e.g. Laptop)

Reserved
To USB HDMI Captuer

USB to UART
for KVM SBC sending ctrl-signal to KVM

Guest USB Port (HID) Guest USB HID Emulator
Convert bytecode to HID payload

USB device mode for guest system (e.g. headless PC)

DSR# 10 RI#11 DCD# 12 DTR# 13 RTS# 14 R232 15 VCC 16

DEF 10 SET 11 UD+ 12 UD- 13 GND 14 VCC 15 V33 16

USB HDMI Capture Card
Connect MS2109 USB Capture Device

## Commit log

2025-12-21 init commit
    [BOM_USB-KVM_2025-12-02.csv, PickAndPlace_PCB_USB-KVM_2025-12-15.csv, base.ipt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]
2026-02-19 Add v1.1 PCB design
    [BOM_USB-KVM_2025-12-02.csv, BOM_USB-KVM_2026-02-19.csv, PickAndPlace_PCB_USB-KVM_2025-12-15.csv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]
2026-02-26 Add paste confirmation, settings & macOS hotkeys
    - Add advance setting dropdown menu
    - Add invert scroll wheel direction option (for mac <--> windows control)
    - Add ask on paste function
    - Add macOS quick access hotkeys
2026-03-08 Add section for buying a ready-to-use device
    Added a section for purchasing a ready-to-use DezKVM Go device from Tindie.
2026-03-08 Add open frame case design
    [base-open-frame.ipt, base-open-frame.stl]
2026-03-14 Add settings overlay and refactor input settings
    Introduce a full Settings overlay (src/www/settings.html) and wire it into index.html. Replace the old advanced-settings dropdown with a Settings button and a dedicated CTRL↔CMD toggle. Refactor local-kvm.js to centralize runtime flags and handlers (invertScrollEnabled, relativeMouseEnabled, relativeMouseSensitivity, ctrlCmdSwapEnabled, askOnPasteEnabled), add functions to toggle settings (toggleSettingsOverlay, toggleRelativeMouseMode, toggleCtrlCmdSwap, toggleInvertScrollwheel, toggleAskOnPaste, toggleMouseJiggler, resetRemoteHID, setMouseJigglerEnabled), and ensure keyboard/mouse logic respects these flags (swapCtrlCmd usage, scaled relat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
2026-03-17 Optimize video capture device start flow
2026-04-13 Add DezKVM-Go gen2 3d models
    [cover-gen2.ipt, cover-gen2.stl, gen2-hdmi-mount.ipt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]
2026-07-28 Add ChromeBook support and improve error UX
    - Add isChromeBook() detection to handle ChromeOS not exposing VID:PID in device labels; falls back to matching generic 'USB Video'/'USB Audio' labels
    - Log all found devices on stream start for easier debugging
    - Include unrecognized device list in the 'device not found' toast message
    - Replace bare alert() with styled toast for stream failure error
2026-08-11 Prioritize exact local KVM device matches
    Replace regex with proper for loop to provide a exact match first find device logic
2026-08-11 Add manual video input selector with preview
    Introduces a Settings > Display video device override flow with device dropdown, live preview, and confirm/cancel actions.
2026-08-25 Add manual video input override and preview
    Introduces a new Settings > Display video device selector with live preview
2026-11-12 kvmterm: skip black frames while the capture card warms up
    The MS2109 emits all-black frames for about 1.5-2s each time its stream
    is opened after being idle (about 10 frames in YUYV at 10 fps, about 50
    in MJPEG at 60 fps). Grab() starts a fresh ffmpeg per frame and used the
    first frame, so the first grab after any pause was black. In particular
    the calibration frames were black, which made calibration "succeed" with
    a meaningless grid and blank glyph templates.
    Keep reading frames until one contains a non-black pixel, giving up
    after 4s (a genuinely black remote screen then returns the last frame).
    When the device is already streaming, the first frame is used as before.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
2026-11-12 kvmterm: reject blank calibrations instead of caching them
    When calibration ran on a frame with no text (e.g. a black frame from
    the capture card, or a remote that was not at a shell prompt), grid
    detection found nothing and fell back to the smallest allowed cell size
    (4x8), which passed the sanity check. The resulting blank glyph
    templates were saved to the calibration cache, and every later run
    loaded them and rendered every inked cell as '?', with no hint that
    recalibration was needed.
    Fail calibration when the lattice frame has almost no ink or when any
    printable glyph template is blank, and treat a cached calibration with
    blank templates as unusable so that it is recalibrated.
    Co-auth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
